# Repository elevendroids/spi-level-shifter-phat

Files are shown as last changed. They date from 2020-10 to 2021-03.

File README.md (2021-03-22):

# SPI Level Shifter pHAT

An expansion board for Raspberry Pi Zero / 2 / 3 / 4 and other pin-compatible SBCs.

Provides a configurable SPI interface with a level shifter to communicate with 3.3V and 1.8V logic level devices.

In addition, this board can also be used as a SPI NOR Flash in-system programmer - target power supply and interface can be controlled in software to avoid interference with a running system.

# Features

- independent 3.3V and 1.8V power supplies, target voltage selectable by a jumper
- high speed logic level translator - rated up to 380Mbit/s (Note that the actual max. speed is limited by the SBC's capabilities, length and quality of the connection cable to the target and the target itself)
- support for powered-off operation - the interface stays isolated while either the SBC is powered off or the interface is disabled by software
- configurable interface control: the translator and target power supply may be disabled by either one of two different GPIO pins or may be enabled permanently
- selectable /CS pin source: SPI0 /CE0, SPI0 /CE1 or GPIO6 (on RPi)
- 6-pin IDC target connector, pin-compatible with the standard 8-pin ISP connector for SPI NOR Flash memories

Designed in KiCad 5.1.7

PCB render:
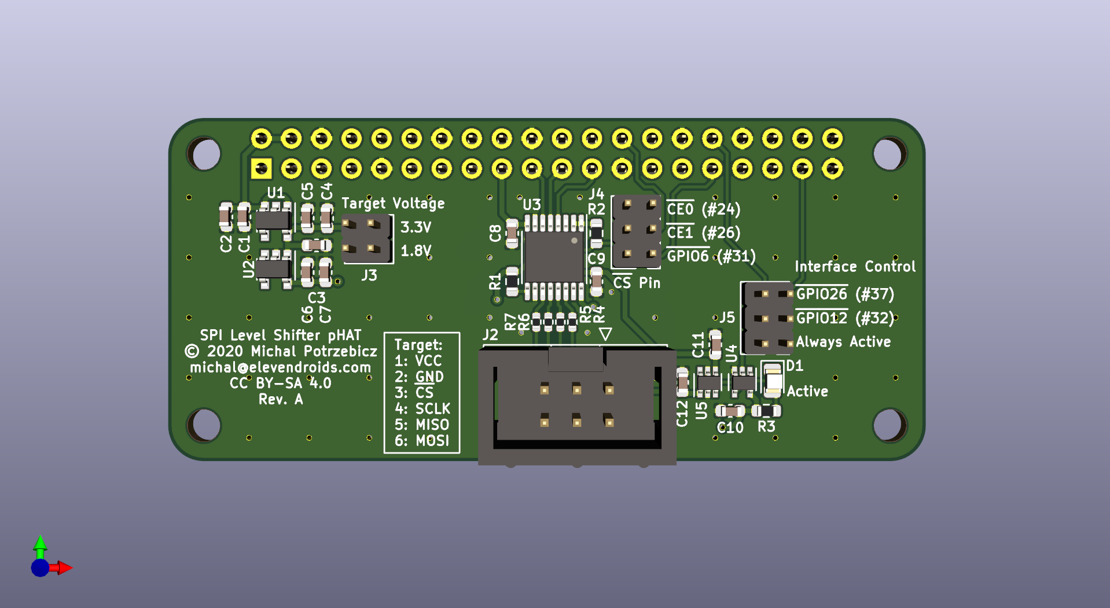
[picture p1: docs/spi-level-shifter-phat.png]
PCB Render


Prototype PCB:
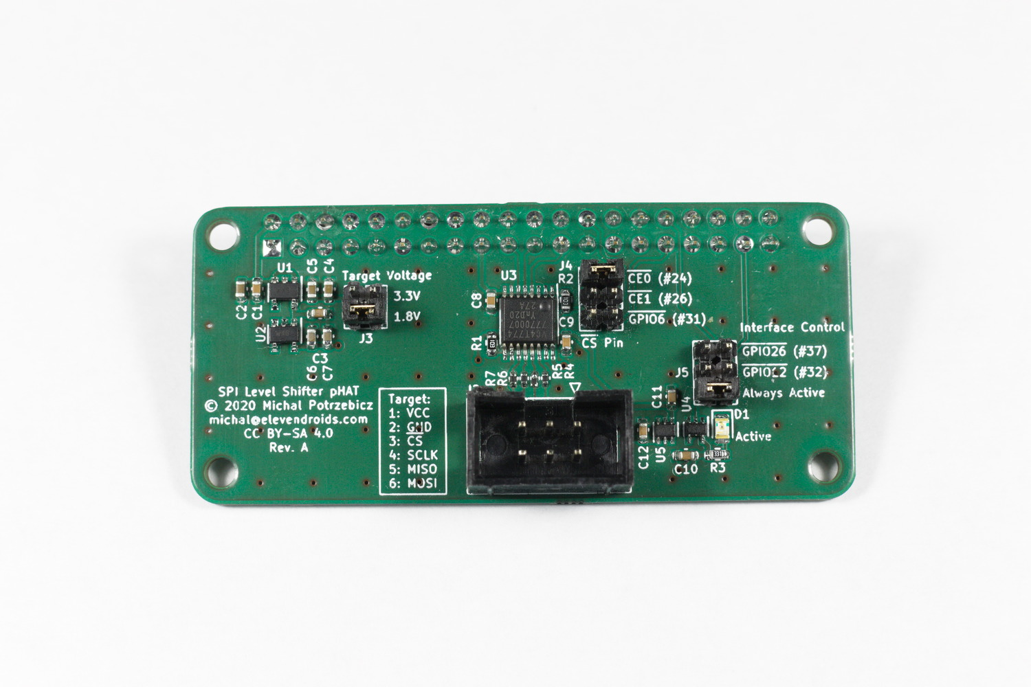
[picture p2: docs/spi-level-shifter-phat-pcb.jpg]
Prototype


Schematic: [PDF](docs/spi-level-shifter-phat.pdf)

License: [CC BY-SA 4.0](https://creativecommons.org/licenses/by-sa/4.0/)

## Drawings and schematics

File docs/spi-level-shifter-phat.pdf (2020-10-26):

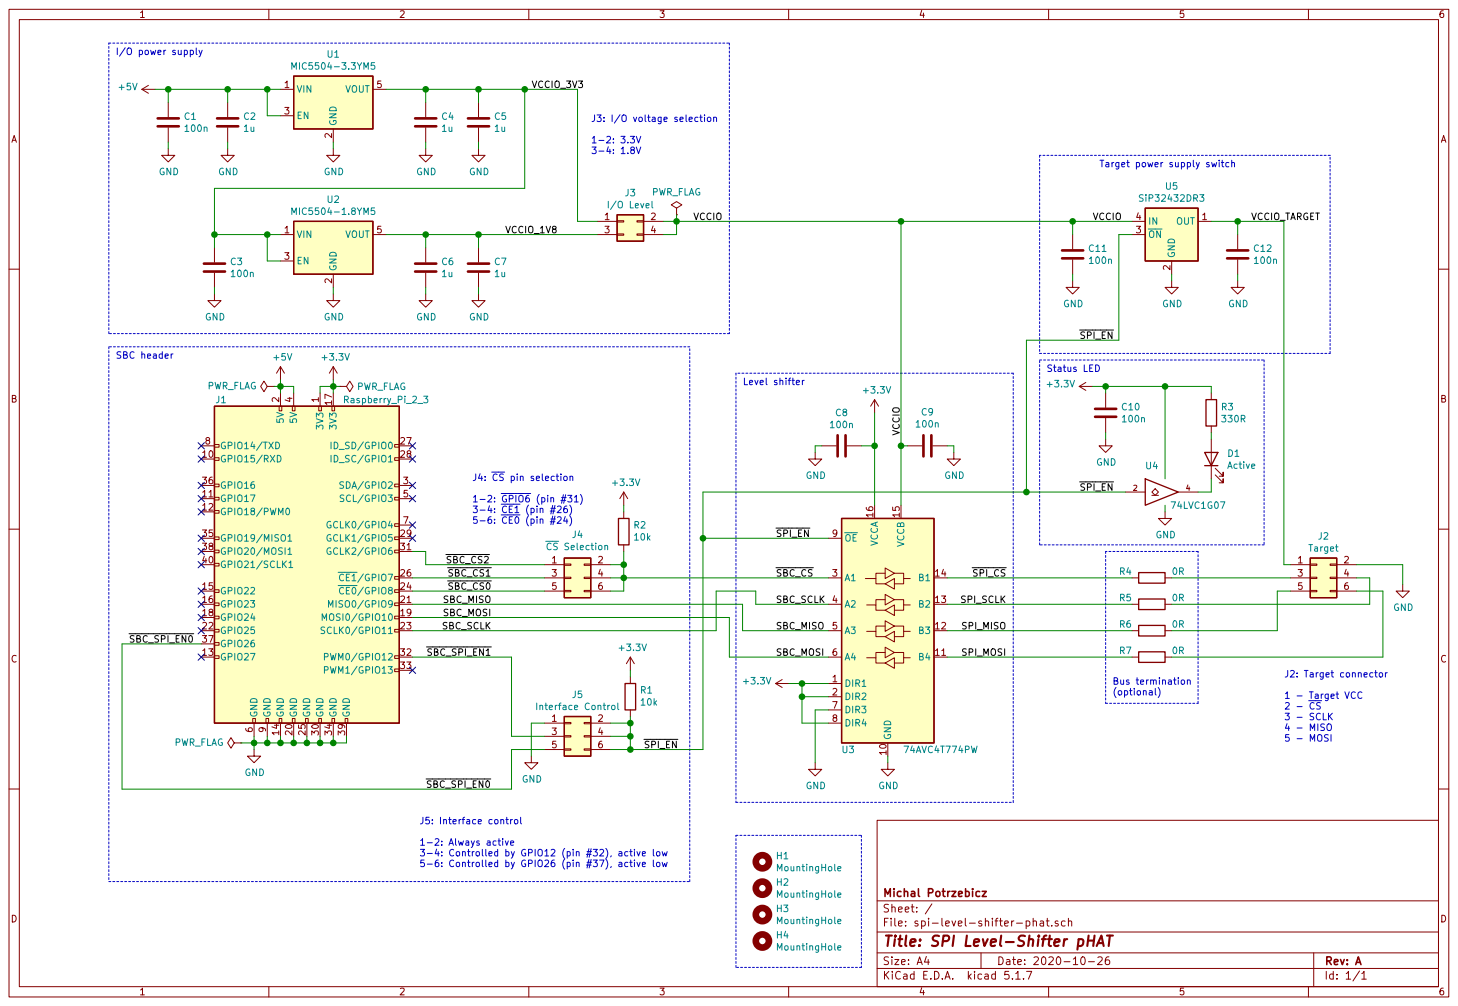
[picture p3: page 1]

Target power supply switch

SBC_MOSI SBC_SCLK | | SBC_MISO

J5: Interface control 1-2: Always active

3-4: Controlled by GPIO12 (pin #32), active low
5-6: Controlled by GPIO26 (pin #37), active low

Id: 1/1 Title: SPI Level-Shifter pHAT

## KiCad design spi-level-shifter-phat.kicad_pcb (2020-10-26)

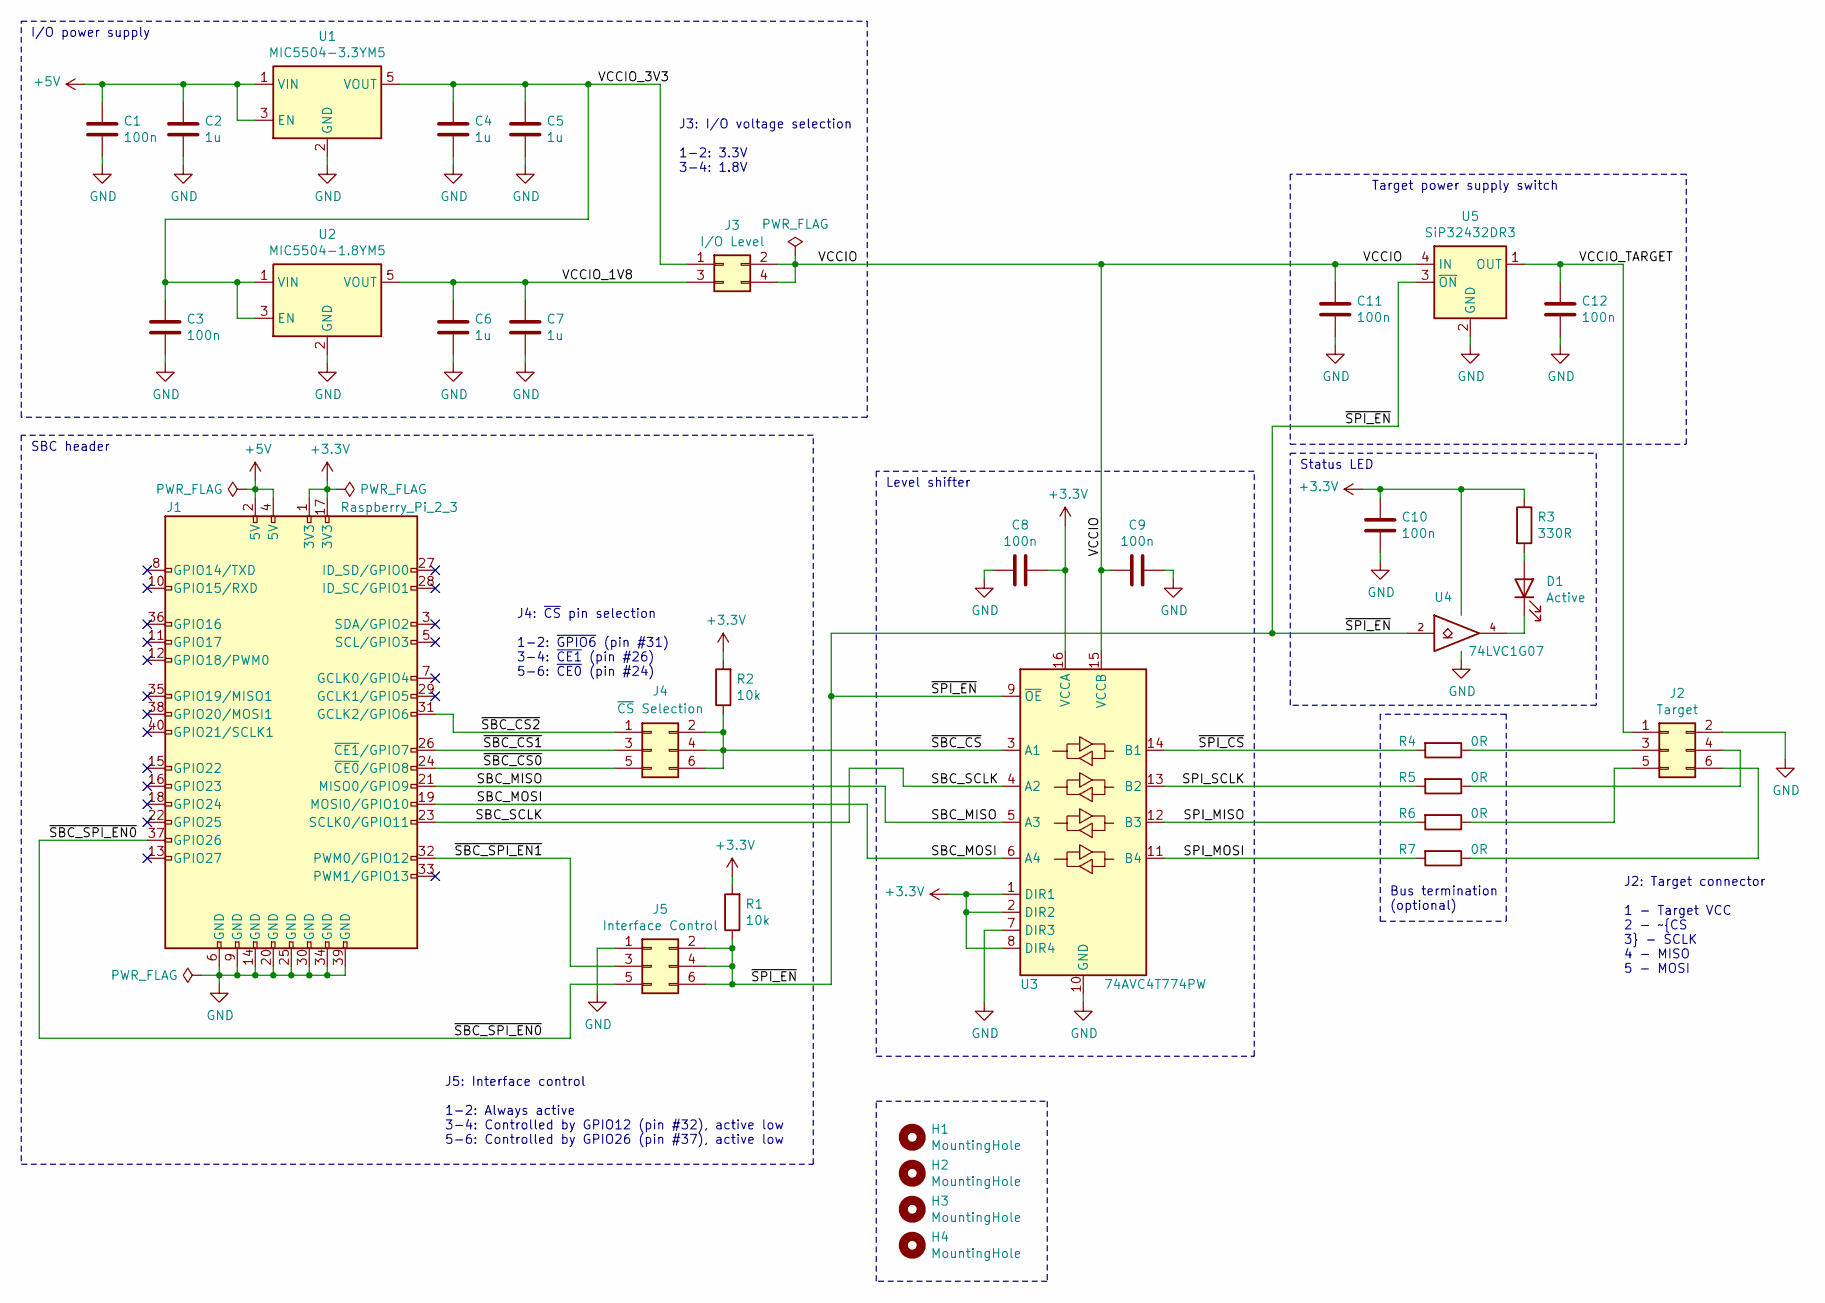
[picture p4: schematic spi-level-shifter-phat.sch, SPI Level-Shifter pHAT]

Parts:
C1, C3, C8, C9, C10, C11, C12: 100n; C_0603_1608Metric
C2, C4, C5, C6, C7: 1u; C_0603_1608Metric
D1: Active; LED_0805_2012Metric
H1, H2, H3, H4: MountingHole; MountingHole_2.7mm_M2.5
J1: Raspberry_Pi_2_3; PinSocket_2x20_P2.54mm_Vertical
J2: Target; IDC-Header_2x03_P2.54mm_Vertical
J3: I/O Level; PinHeader_2x02_P2.00mm_Vertical
J4: ~CS~ Selection; PinHeader_2x03_P2.00mm_Vertical
J5: Interface Control; PinHeader_2x03_P2.00mm_Vertical
R1, R2: 10k; R_0603_1608Metric
R3: 330R; R_0603_1608Metric
R4, R5, R6, R7: 0R; R_0402_1005Metric
U1: MIC5504-3.3YM5; SOT-23-5
U2: MIC5504-1.8YM5; SOT-23-5
U3: 74AVC4T774PW; TSSOP-16_4.4x5mm_P0.65mm
U4: 74LVC1G07; SOT-353_SC-70-5
U5: SiP32432DR3; SOT-363_SC-70-6

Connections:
+3V3: C8.1, C10.1, J1.1 (3V3), J1.17 (3V3), R1.2, R2.2, R3.1, U3.1 (DIR1), U3.2 (DIR2), U3.8 (DIR4), U3.16 (VCCA), U4.5 (VCC)
+5V: C1.1, C2.1, J1.2 (5V), J1.4 (5V), U1.1 (VIN), U1.3 (EN)
/SBC_MISO: J1.21 (MISO0/GPIO9), U3.5 (A3)
/SBC_MOSI: J1.19 (MOSI0/GPIO10), U3.6 (A4)
/SBC_SCLK: J1.23 (SCLK0/GPIO11), U3.4 (A2)
/SPI_MISO: R6.2, U3.12 (B3)
/SPI_MOSI: R7.2, U3.11 (B4)
/SPI_SCLK: R5.2, U3.13 (B2)
/VCCIO: C9.1, C11.1, J3.2, J3.4, U3.15 (VCCB), U5.4 (IN)
/VCCIO_1V8: C6.1, C7.1, J3.3, U2.5 (VOUT)
/VCCIO_3V3: C3.1, C4.1, C5.1, J3.1, U1.5 (VOUT), U2.1 (VIN), U2.3 (EN)
/VCCIO_TARGET: C12.1, J2.1, U5.1 (OUT)
/~SBC_CS: J4.2, J4.4, J4.6, R2.1, U3.3 (A1)
/~SBC_CS0: J1.24 (~CE0~/GPIO8), J4.5
/~SBC_CS1: J1.26 (~CE1~/GPIO7), J4.3
/~SBC_CS2: J1.31 (GCLK2/GPIO6), J4.1
/~SBC_SPI_EN0: J1.37 (GPIO26), J5.5
/~SBC_SPI_EN1: J1.32 (PWM0/GPIO12), J5.3
/~SPI_CS: R4.2, U3.14 (B1)
/~SPI_EN: J5.2, J5.4, J5.6, R1.1, U3.9 (~OE), U4.2, U5.3 (~ON)
GND: C1.2, C2.2, C3.2, C4.2, C5.2, C6.2, C7.2, C8.2, C9.2, C10.2, C11.2, C12.2, J1.6 (GND), J1.9 (GND), J1.14 (GND), J1.20 (GND), J1.25 (GND), J1.30 (GND), J1.34 (GND), J1.39 (GND), J2.2, J5.1, U1.2 (GND), U2.2 (GND), U3.7 (DIR3), U3.10 (GND), U4.3 (GND), U5.2 (GND), U5.5 (GND)
unnamed: D1.1 (K), U4.4
unnamed: D1.2 (A), R3.2
unnamed: J2.3, R4.1
unnamed: J2.4, R5.1
unnamed: J2.5, R6.1
unnamed: J2.6, R7.1

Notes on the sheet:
Target power supply switch
J2: Target connector 1 - Target VCC 2 - ~CS 3 - SCLK 4 - MISO 5 - MOSI
Bus termination (optional)
Status LED
I/O power supply
Level shifter
SBC header
J5: Interface control 1-2: Always active 3-4: Controlled by GPIO12 (pin #32), active low 5-6: Controlled by GPIO26 (pin #37), active low
J4: ~CS~ pin selection 1-2: ~GPIO6~ (pin #31) 3-4: ~CE1~ (pin #26) 5-6: ~CE0~ (pin #24)
J3: I/O voltage selection 1-2: 3.3V 3-4: 1.8V

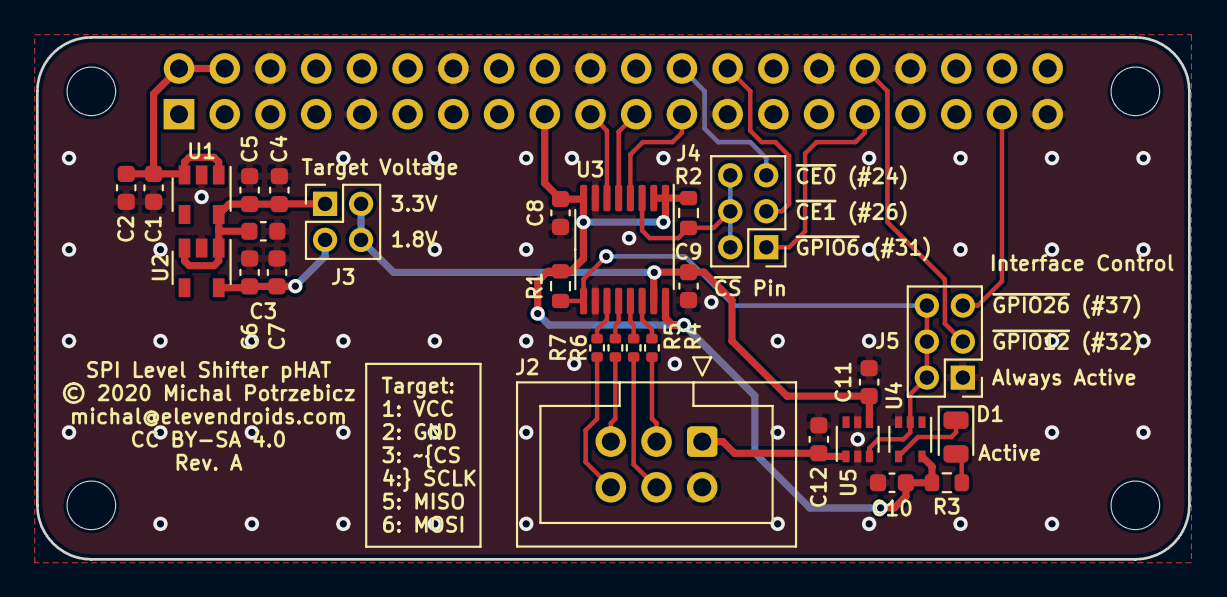
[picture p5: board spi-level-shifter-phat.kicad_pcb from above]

Board: 2 copper layers, 64.0 x 29.0 mm, 34 parts (1 on the bottom side), 27 nets.

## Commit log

2021-03-22 Updated README, added photo of a prototype
2021-04-07 Updated schematic due to library changes to 74AVC4T774PW
    [spi-level-shifter-phat.sch]

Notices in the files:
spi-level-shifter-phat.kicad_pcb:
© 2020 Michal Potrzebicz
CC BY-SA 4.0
